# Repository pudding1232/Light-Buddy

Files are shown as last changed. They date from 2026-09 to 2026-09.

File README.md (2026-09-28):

# Light Buddy: Adjustable Flashlight Arm

**An articulating, tool-free arm that holds a pocket flashlight so you can light up a work area and keep both hands free.**

<p align="center">
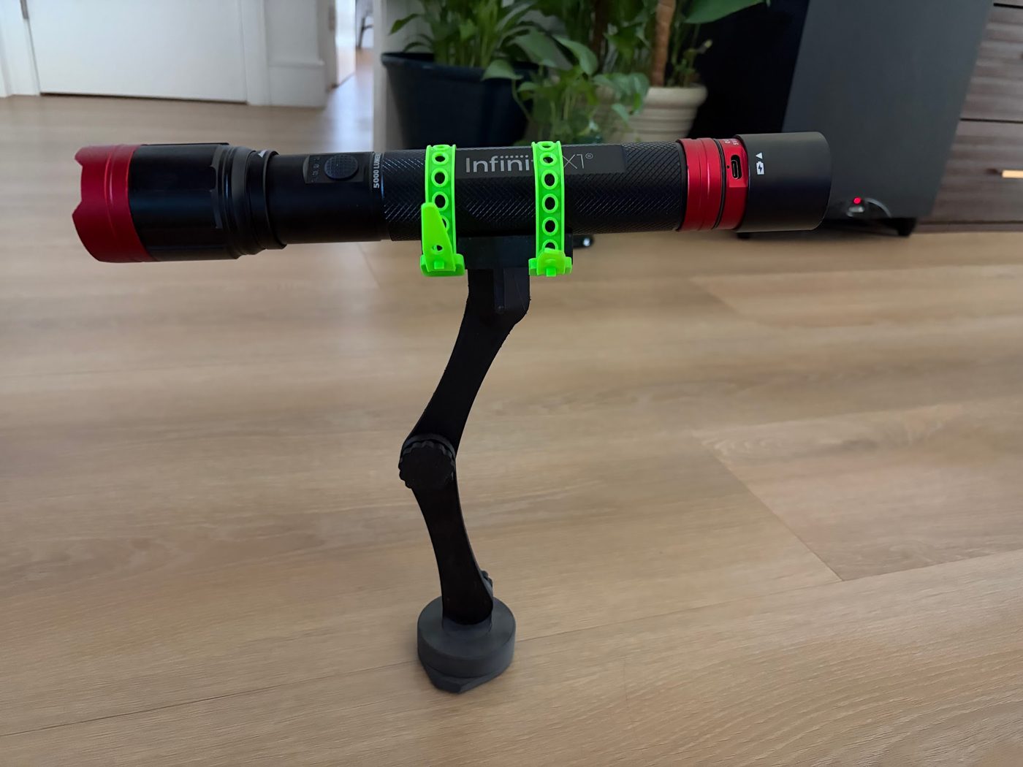
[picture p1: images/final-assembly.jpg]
Final Light Buddy assembly holding a flashlight
  
</p>

| | |
|---|---|
| **Team** | Tran Gia Huy Pham (sole CAD designer), Robert Lopez, Leonardo Valenti |
| **Context** | DMT 56 team project, Critical Design Review (CDR), Spring 2026 |
| **Processes** | FDM (Markforged Onyx + continuous carbon fiber), SLS (Nylon 12), FDM TPU, PolyJet |
| **CAD** | Autodesk Fusion 360: part modeling, assembly, technical drawing, rendered animation |
| **Outcome** | Functional prototype, 114.71 cc total part volume, about $23.88 material cost per unit |

---

## My role

I was the **sole CAD designer** on a three-person team. I modeled every part and the full assembly in **Fusion 360**:

- Designed all components: arm links with **Hirth gear joints**, thumbscrews, the **ratcheting base** with magnet pockets and a removable cap, and the **V-block holder** with integrated strap buckles.
- Carried the design through **three prototype iterations**, reworking the geometry after each round of printing and testing.
- Applied **DfAM** changes, including support structures modeled into the V-block and a locating lip on the base.
- Produced the **assembly drawing with parts list** ([docs/arm-link-assembly-drawing.png](docs/arm-link-assembly-drawing.png)), the renders, and the exploded-view animation.
<!-- Optional: add anything else you personally did (printing, testing, cost analysis). -->

---

## The problem

> *"Design an adjustable arm that allows the user to securely hold a variety of small flashlights in order to illuminate a specific area."*

Professionals and hobbyists often carry a pocket flashlight, but holding it ties up a hand. Light Buddy mounts on a surface, grips a range of flashlight sizes, and can be aimed and locked in place. That leaves both hands free for the work.

## Final design

<p align="center">
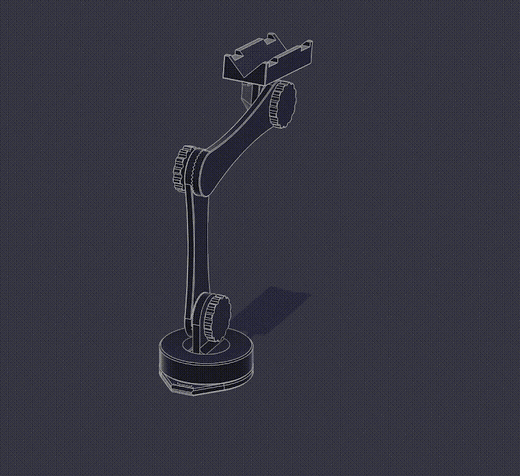
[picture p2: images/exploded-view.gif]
Animated exploded view of the assembly
  
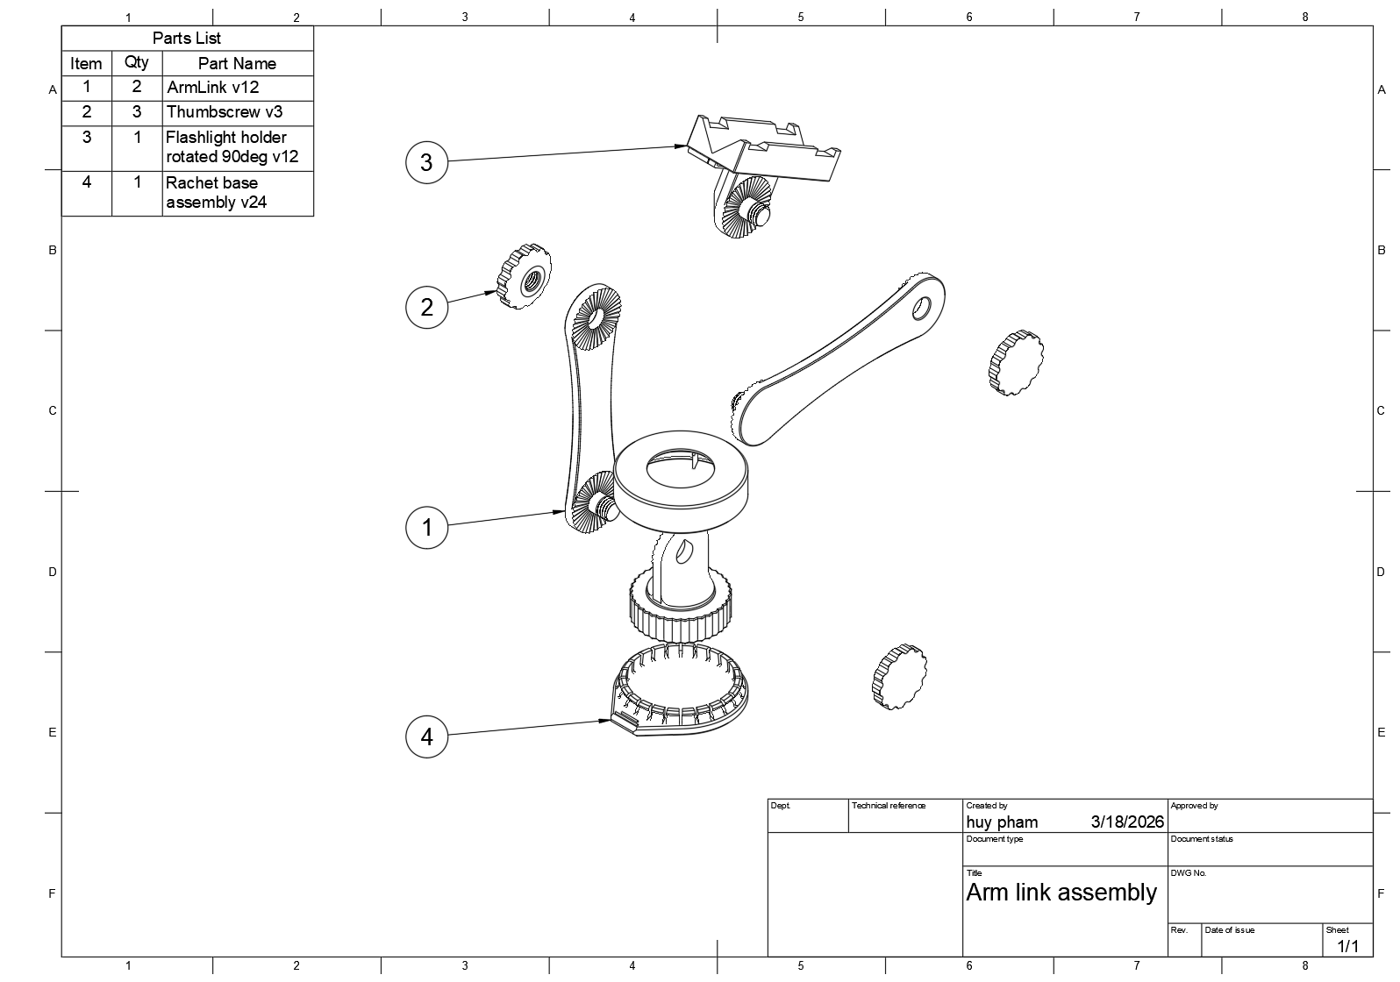
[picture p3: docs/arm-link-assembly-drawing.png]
Arm link assembly drawing with parts list
  
</p>

| Feature | Why it's there |
|---|---|
| **Ratcheting base with removable cap** | Rotates in fixed steps. The cap can be swapped for future base designs. Pockets for insert magnets let it mount on ferrous surfaces. |
| **Hirth gear joints** | Serrated face gears lock at discrete angles, so the arm holds its aim under load. The design is modular, so links can be added to extend the reach. |
| **Thumbscrews** | Every joint adjusts by hand, with no tools needed. |
| **V-block mount + TPU straps** | The V-shape self-centers round bodies of different diameters. Integrated strap buckles clamp the light in place. |

**Parts list:** 2× arm link, 3× thumbscrew, 1× flashlight holder (V-block), 1× ratchet base assembly.

---

## Design iterations

### Prototype V1: proving the joints

<p>
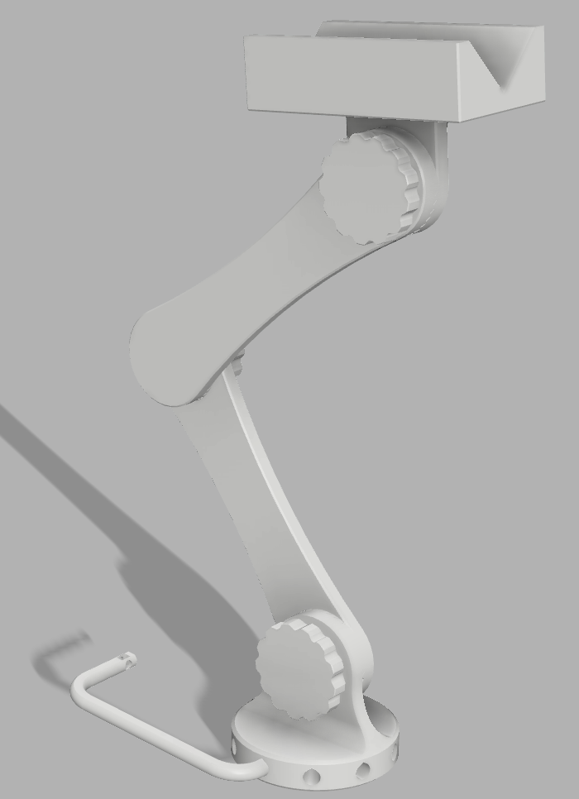
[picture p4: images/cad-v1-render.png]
V1 CAD render
  
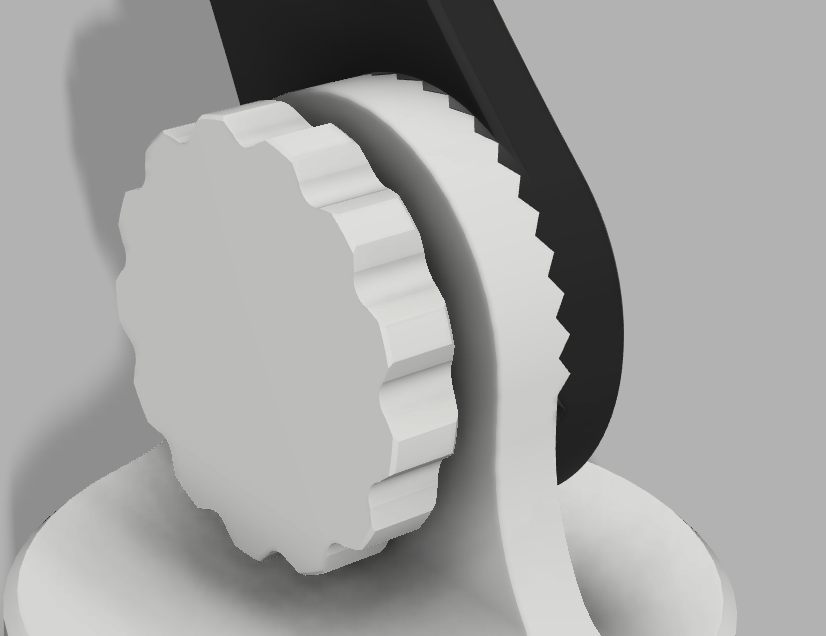
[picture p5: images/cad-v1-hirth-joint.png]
V1 Hirth joint
  
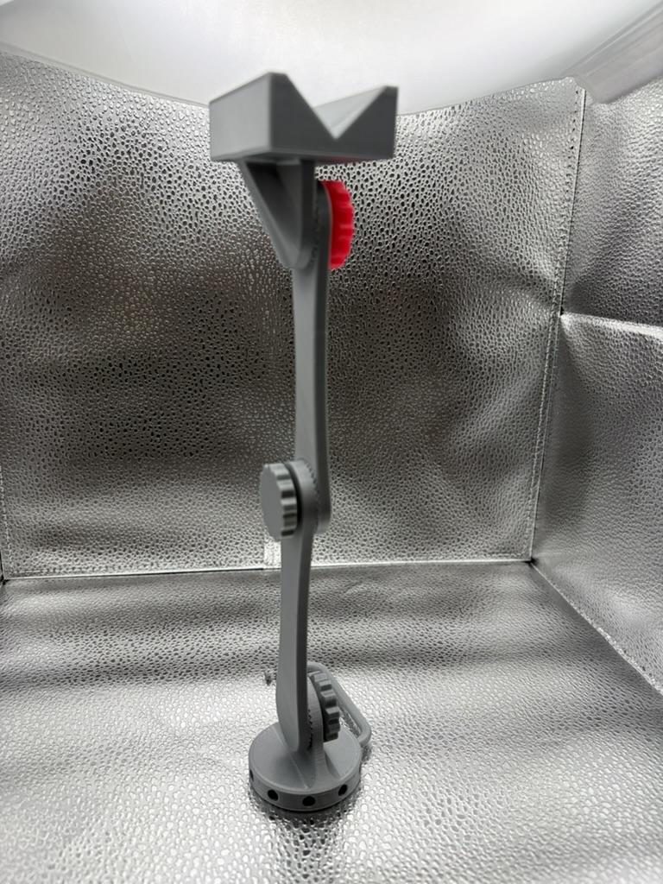
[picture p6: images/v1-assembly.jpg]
V1 printed assembly
  
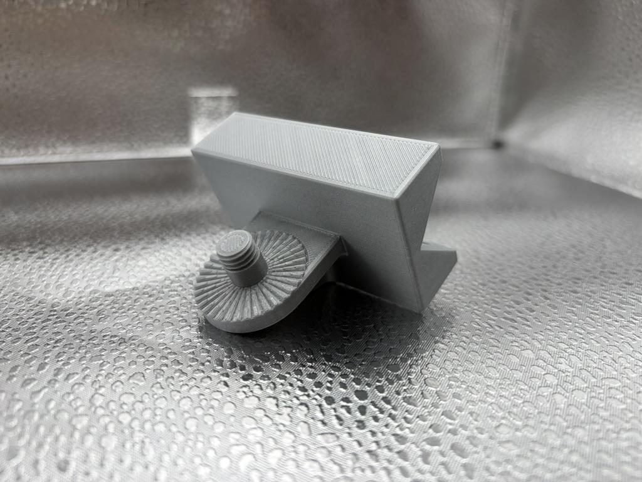
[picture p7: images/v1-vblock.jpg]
V1 printed V-block
  
</p>

- ✅ The Hirth gears and threads worked well.
- ❌ The V-block was bulky, and the base wasn't very functional.

### Prototype V2: a better base and a smaller holder

<p>
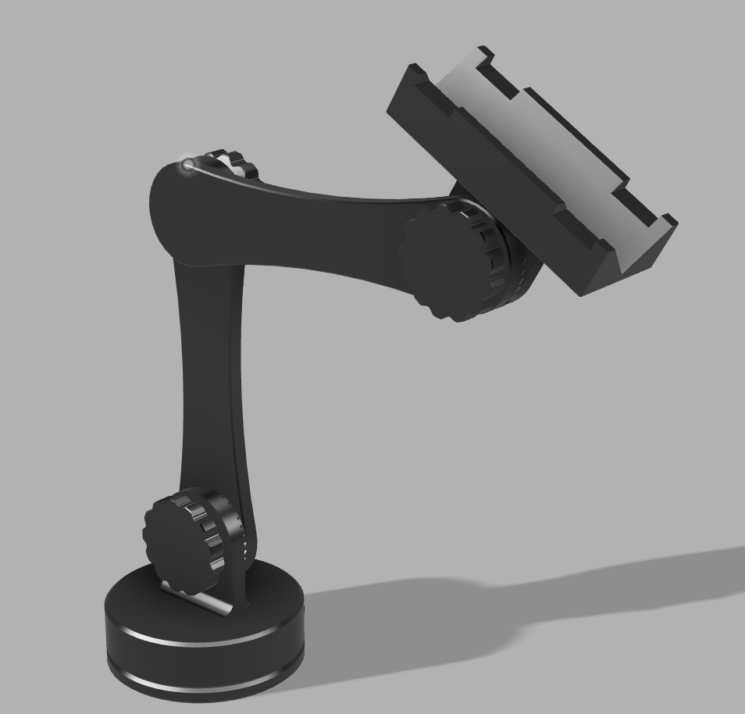
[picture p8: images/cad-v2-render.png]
V2 CAD render
  
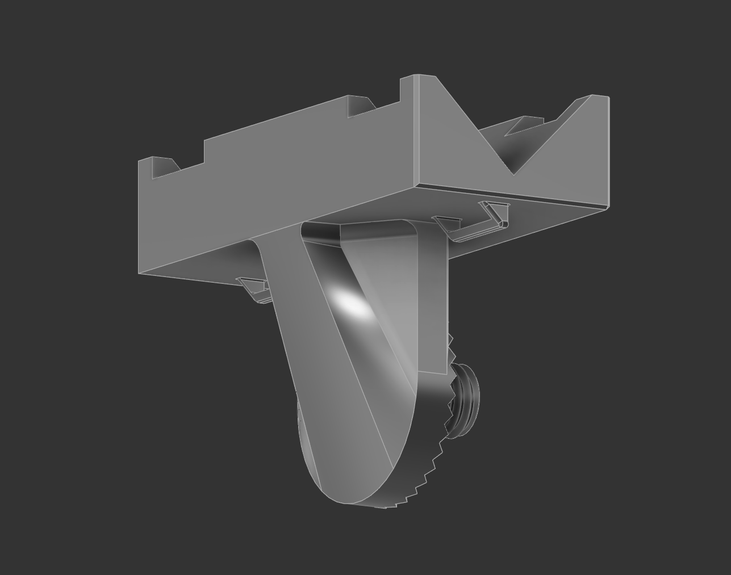
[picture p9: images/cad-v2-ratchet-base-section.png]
V2 ratcheting base section
  
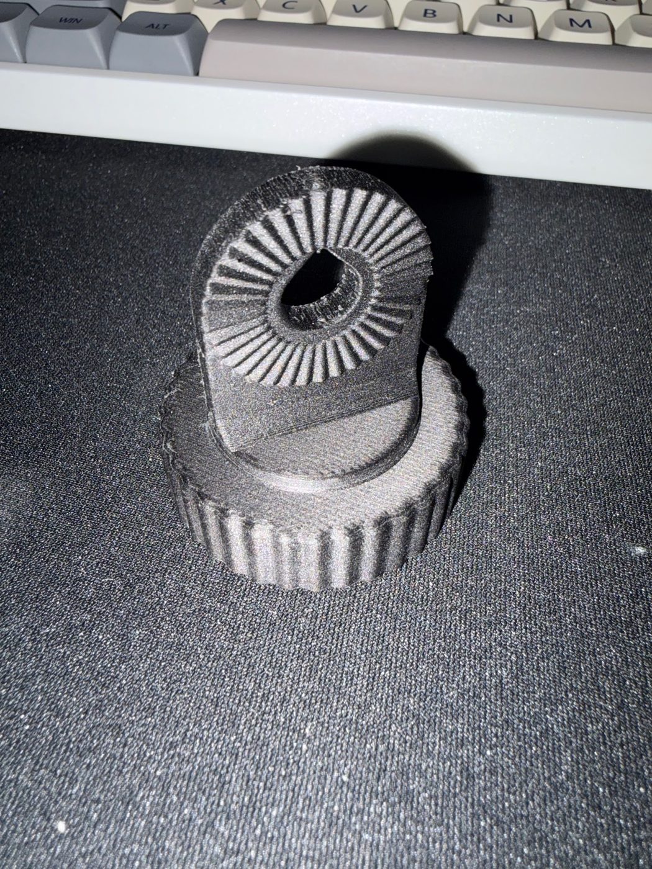
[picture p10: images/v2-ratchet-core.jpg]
V2 printed ratchet core
  
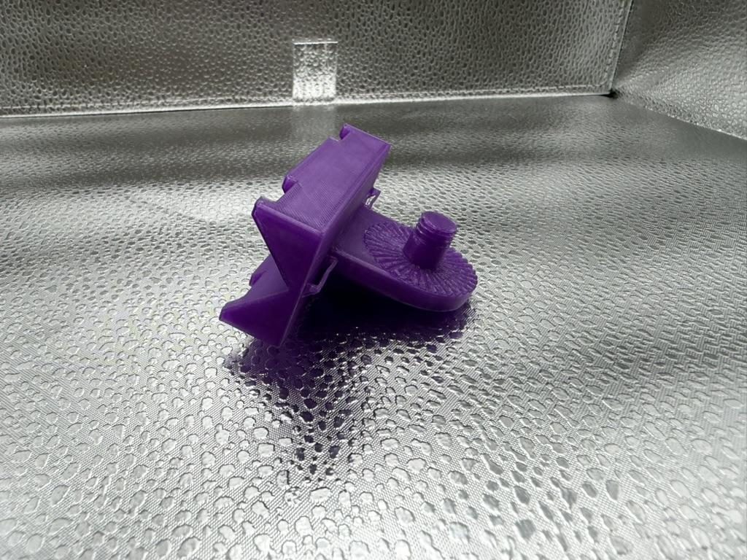
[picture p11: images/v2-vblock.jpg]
V2 printed V-block
  
</p>

- Added a **ratcheting base with integrated magnets**.
- Made the V-block smaller and added **strap loops** to the holder.

### Prototype V3: designing for manufacturing

<p>
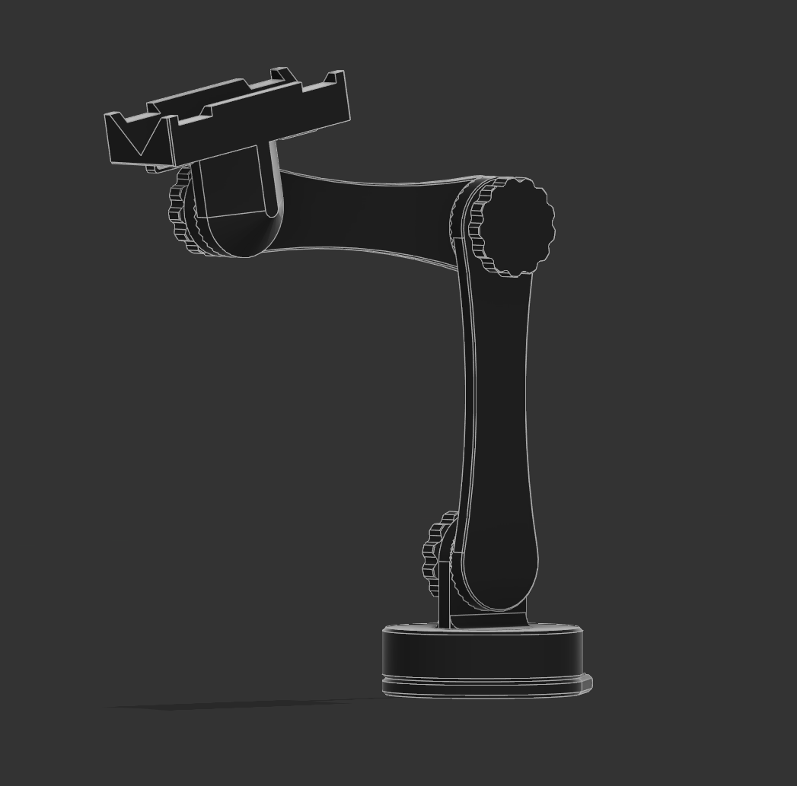
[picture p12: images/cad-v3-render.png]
V3 CAD render
  
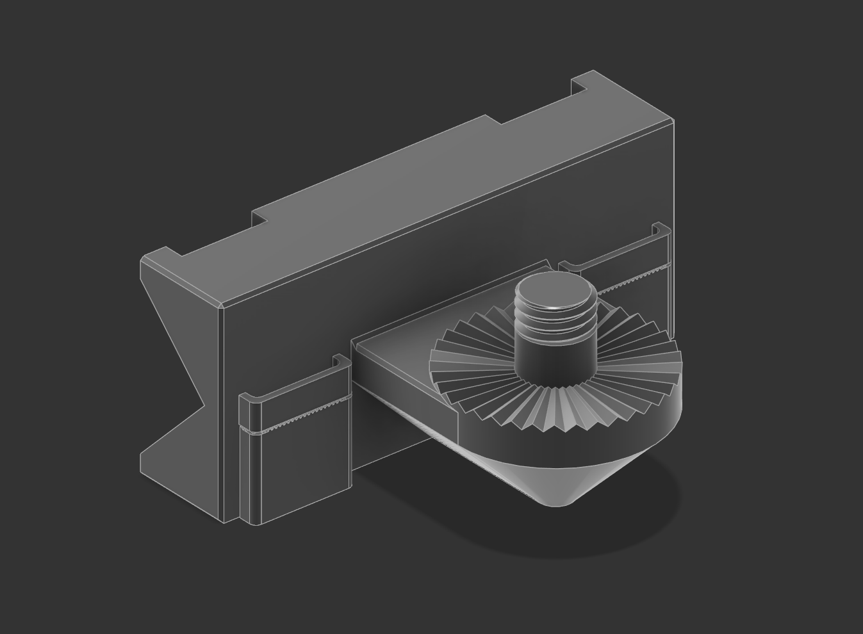
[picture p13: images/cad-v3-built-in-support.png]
V3 built-in support
  
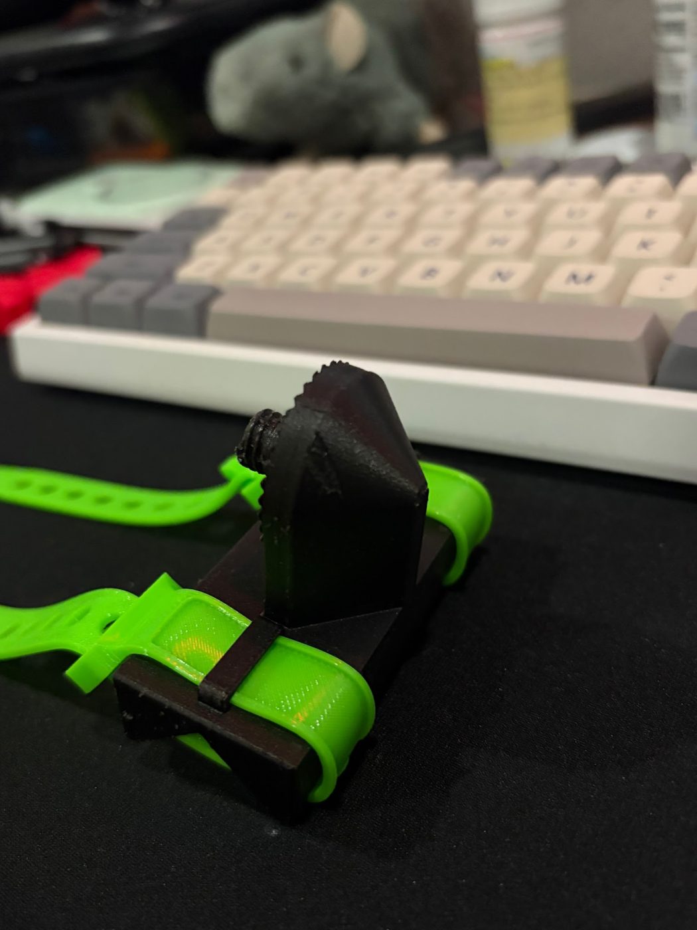
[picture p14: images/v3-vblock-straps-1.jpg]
V3 V-block with TPU straps
  
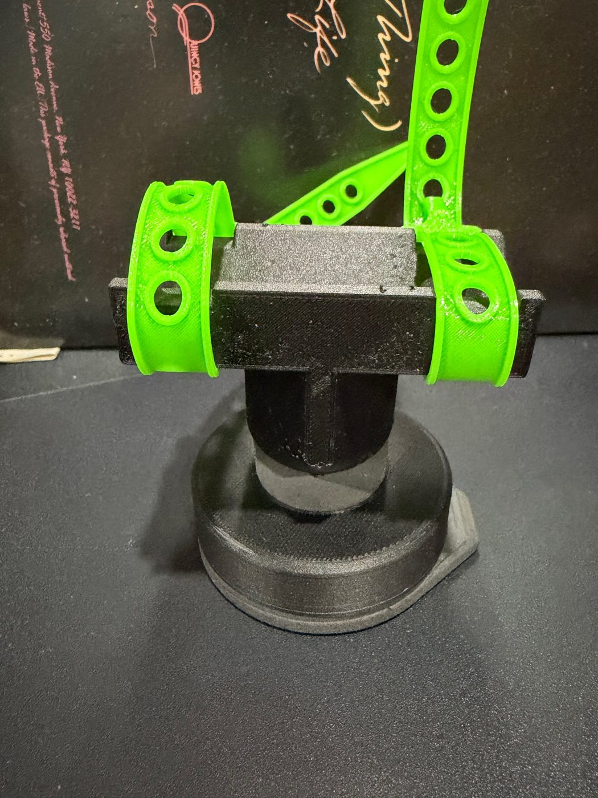
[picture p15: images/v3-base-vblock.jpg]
V3 base and V-block
  
</p>

- Designed **support structures into the V-block model** so it prints cleanly (DfAM).
- Added a **lip to the base** so bases can be swapped more easily.

### V-block evolution (V1 → V3)

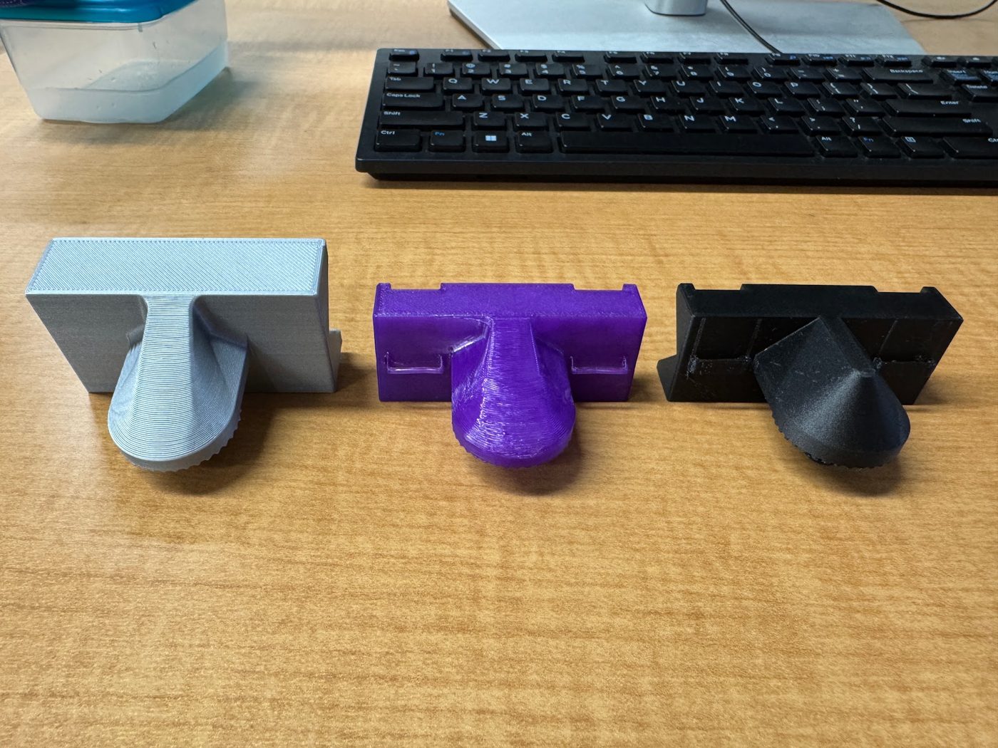
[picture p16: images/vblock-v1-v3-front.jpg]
V-block versions 1, 2 and 3 side by side


---

## Engineering challenges

**Materials**

- **Onyx with continuous carbon fiber** for the arms, for stiffness so the arm stays rigid once it's locked.
- **Flexible Onyx ears** in the ratcheting base, so the ratchet can click.
- **SLS Nylon 12** for the ratchet core and housing cap, for precision and isotropic strength.
- **TPU 95A** for the straps.

**Design for additive manufacturing**

| Problem | Solution |
|---|---|
| The V-block still needed support material | Designed custom support structures into the part |
| The ratchet base cap was fragile and broke easily because of its FDM print orientation | Switched to **SLS** for isotropic properties |
| The ratchet housing was stiff and hard to tune | Open. See [Next steps](#next-steps) |
| Metric threads don't print well | Open |

**Tolerances:** The thumbscrew threads and ratcheting base were the hardest fits to get right, and results from the Markforged printer were inconsistent between prints.

### Failure analysis

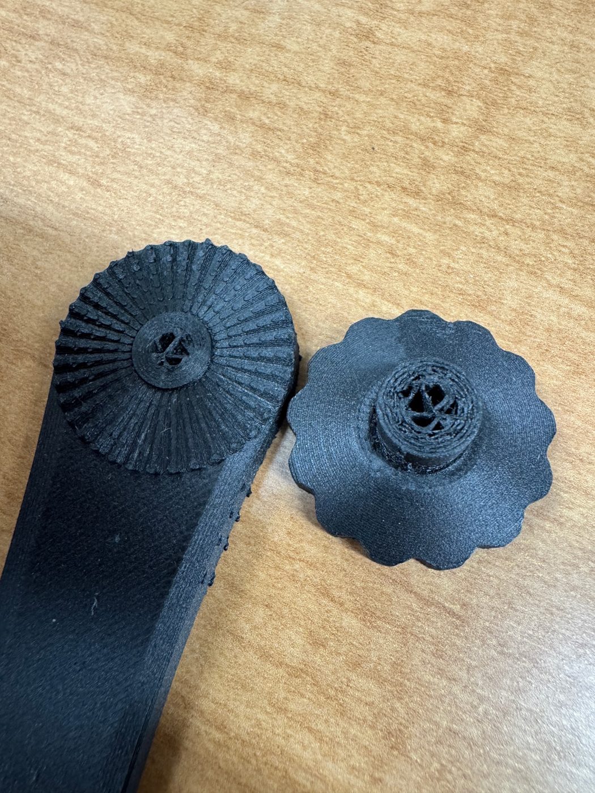
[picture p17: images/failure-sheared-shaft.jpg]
Sheared shaft at the base


Even after the wall count was increased to 6, a shaft **broke near the base**. The cause was poor print accuracy: the threads bound up, and the torque from tightening sheared the shaft. This is why tolerance tuning on the threads became a critical project element.

<br clear="right">

---

## Verification & testing

<p>
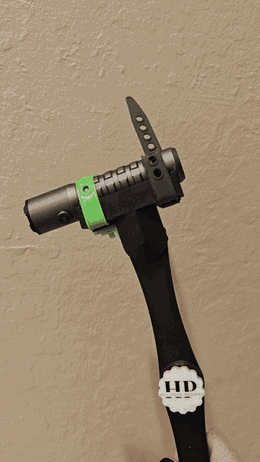
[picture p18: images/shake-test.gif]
Shake test: flashlight stays secured while the arm is shaken
  
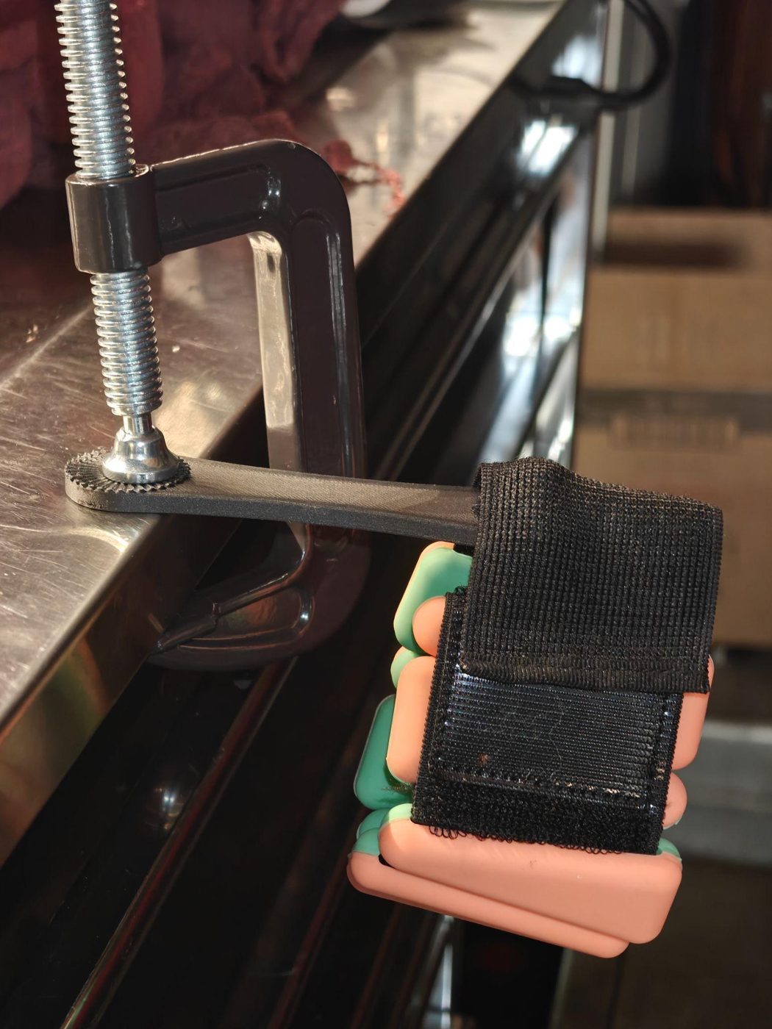
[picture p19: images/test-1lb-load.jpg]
1 lb load test
  
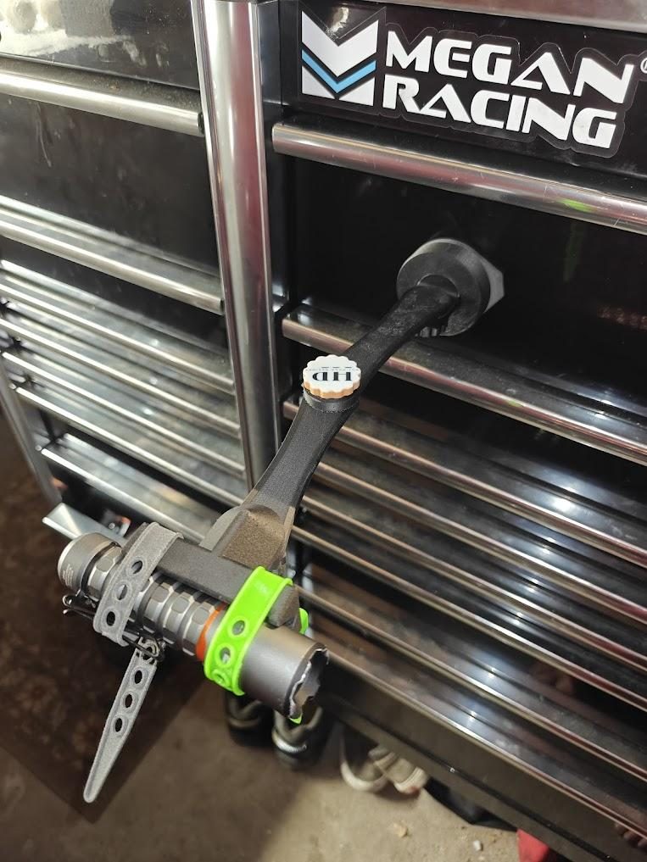
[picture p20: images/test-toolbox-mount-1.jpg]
Mounted magnetically on a toolbox
  
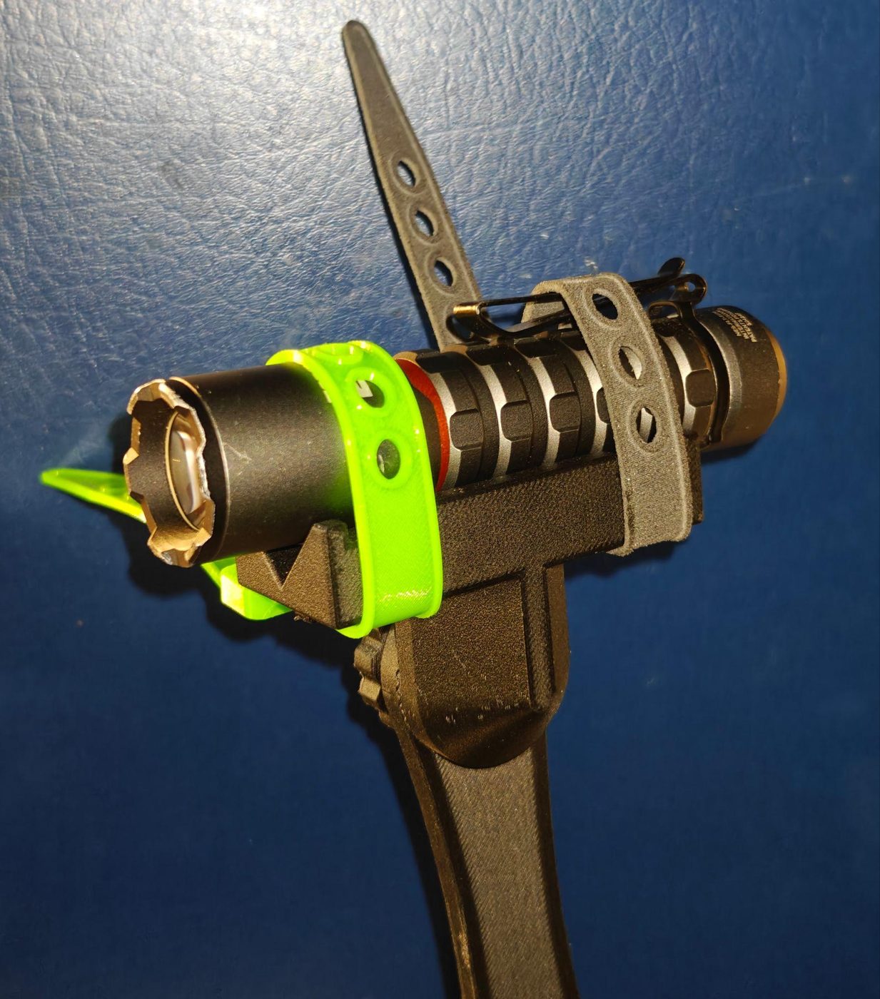
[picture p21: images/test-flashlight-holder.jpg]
Holding a different flashlight
  
</p>

The three critical requirements were: **holds multiple flashlights**, **stays rigid when fixed**, and **can be adjusted repeatedly**. The arm was tested with several flashlights, mounted magnetically on a toolbox, shaken, and loaded with **1 lb**.

| Quantitative requirement | Priority | Result |
|---|---|---|
| Fits within a 5″ × 5″ × 5″ envelope | High | ✅ All dimensions < 5″ |
| Part volume ≤ ⅓ of that envelope (≈ 683 cc) | High | ✅ 114.71 cc (~6% of the envelope) |
| Holds at least 3 types of flashlight | High | ✅ Tested with multiple flashlights |
| Holds about 5 oz | High | ✅ Held 1 lb (16 oz) |
| Joints survive double flashlight weight (about 10 oz) | Medium | ✅ Held 1 lb (16 oz) |
| At least 3 axes of adjustment | Medium | ✅ 3 Hirth joints + rotating ratchet base |
| Setup in about 20 s | Low | ✅ About 10 s |
| Extended arm length about 10 in | Low | ⚠️ About 5 in (see note) |

**Note on arm length:** The arm reaches about 5 in, short of the 10 in target. That target conflicted with two high-priority requirements: the whole product had to fit in a 5″ cube and use no more than a third of its volume. We kept the envelope, and because the arm links are modular, more links can be added for extra reach.

<details>
<summary>Qualitative requirements</summary>

| Requirement | Priority |
|---|---|
| Demonstrates fit with another object, or has multiple components that fit together | High |
| Serves a function other than visual | High |
| Rigid when fixed; doesn't sag over time | High |
| Holds the flashlight firmly; the light stays in place once tightened | High |
| Attaches to multiple surfaces, both magnetic and non-magnetic | Medium |
| Thin folded form factor that fits a medium pocket | Medium |
| Can be adjusted with one hand | Low |
| Collapsible and modular, with swappable parts | Low |
| Simple appearance suitable for professional use | Low |

</details>

---

## Cost & production

| # | Part | Process | Material | Volume (cc) | Cost ($) |
|---|---|---|---|---|---|
| 1 | Arm (×2) | FDM | Onyx + continuous CF | 24.70 + 1.94 CF | 11.68 |
| 2 | Nut (×3) | FDM | Onyx | 7.72 | 1.83 |
| 3 | V-block holder | FDM | Onyx | 18.24 | 4.33 |
| 4 | Ratchet housing | FDM | Onyx | 7.38 | 1.75 |
| 5 | Housing cap | SLS | Nylon 12 | 20.00 | 1.58 |
| 6 | Ratchet core | SLS | Nylon 12 | 26.50 | 2.55 |
| 7 | TPU straps (×2) | FDM | TPU 95A | 8.23 | 0.16 |
| | **Total** | | | **114.71** | **$23.88** |

### Customization concept

<p>
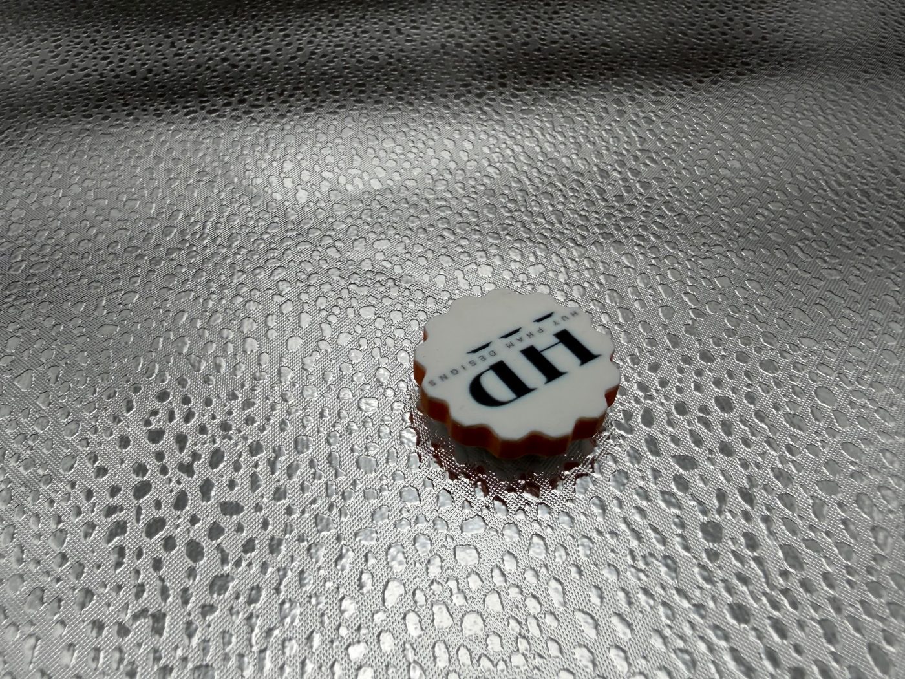
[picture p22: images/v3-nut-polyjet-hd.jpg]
PolyJet printed custom nut
  
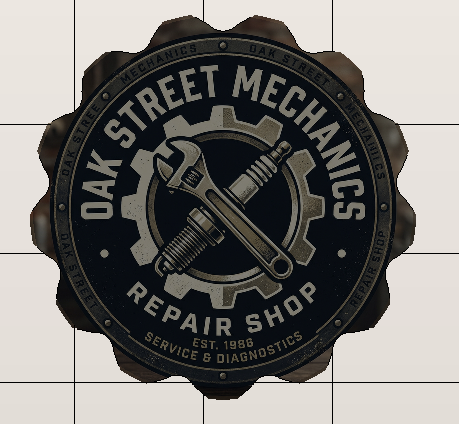
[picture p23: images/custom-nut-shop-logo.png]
Custom nut with shop logo
  
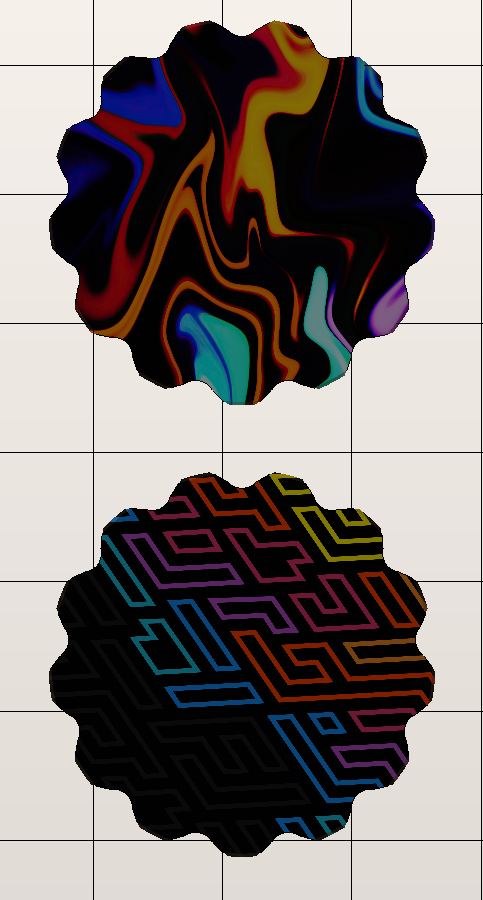
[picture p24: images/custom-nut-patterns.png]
Custom nut patterns
  
</p>

Tradespeople often mark their tools so they don't get mixed up on a job site, and shops like to brand their equipment. Buyers could keep the standard black FDM thumbscrew nuts or pay extra for 1–3 **full-color PolyJet nuts** with a logo or graphic. PolyJet makes one-off customization affordable at a scale that traditional manufacturing can't match.

---

## Next steps

Planned improvements, focused on the base mount:

- A stronger hold
- More mounting styles
- A better ratcheting mechanism, or a set screw
- A grippier base to prevent slipping and rotating

---

## Repository contents

```
light-buddy/
├── README.md
├── cad/        STEP + STL files for each part
├── docs/       Assembly drawing (and CDR slides)
└── images/     Photos, renders, and animations used above
```

## Team

Tran Gia Huy Pham · Robert Lopez · Leonardo Valenti

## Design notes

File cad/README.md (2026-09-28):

# CAD files

Add your exported part files here so reviewers can open them without your CAD software. GitHub shows `.stl` files in an interactive 3D viewer.

Suggested files (names match the assembly drawing):

| Part | Qty | STEP | STL |
|---|---|---|---|
| Arm link | 2 | `arm-link.step` | `arm-link.stl` |
| Thumbscrew nut | 3 | `thumbscrew.step` | `thumbscrew.stl` |
| Flashlight holder (V-block) | 1 | `vblock-holder.step` | `vblock-holder.stl` |
| Ratchet housing | 1 | `ratchet-housing.step` | `ratchet-housing.stl` |
| Ratchet core | 1 | `ratchet-core.step` | `ratchet-core.stl` |
| Housing cap | 1 | `housing-cap.step` | `housing-cap.stl` |
| TPU strap | 2 | `tpu-strap.step` | `tpu-strap.stl` |
| Full assembly | — | `light-buddy-assembly.step` | — |

Keep each file under 100 MB. GitHub blocks larger files.

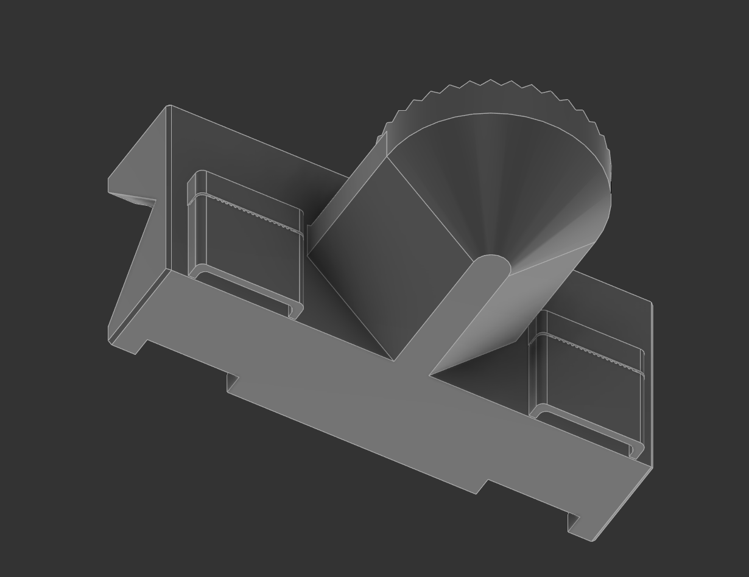
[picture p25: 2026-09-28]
images/cad-v3-support-detail.png

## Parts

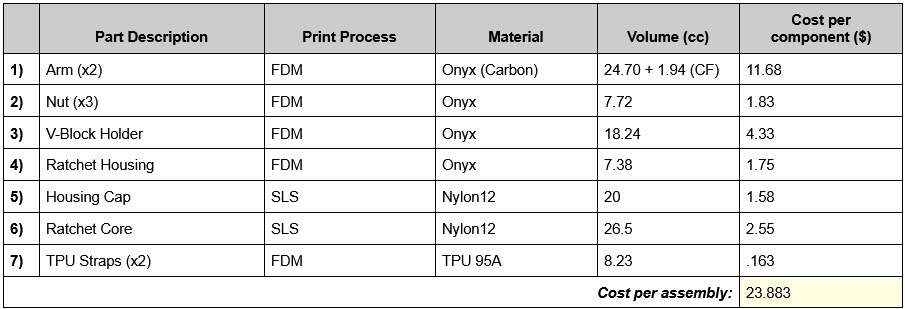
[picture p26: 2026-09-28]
images/cost-table.png

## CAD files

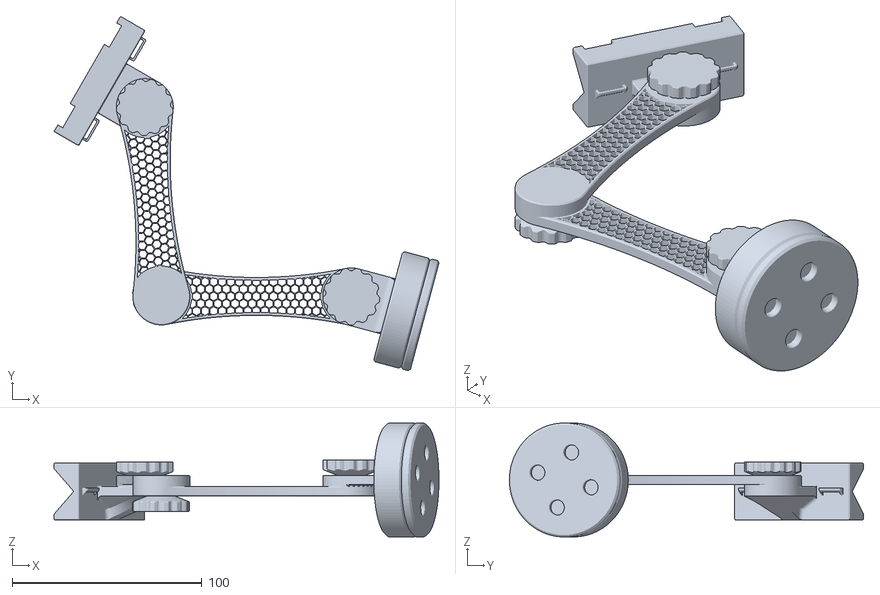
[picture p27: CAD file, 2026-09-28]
cad/Arm link assembly.stl
202.7 x 186.5 x 60.0

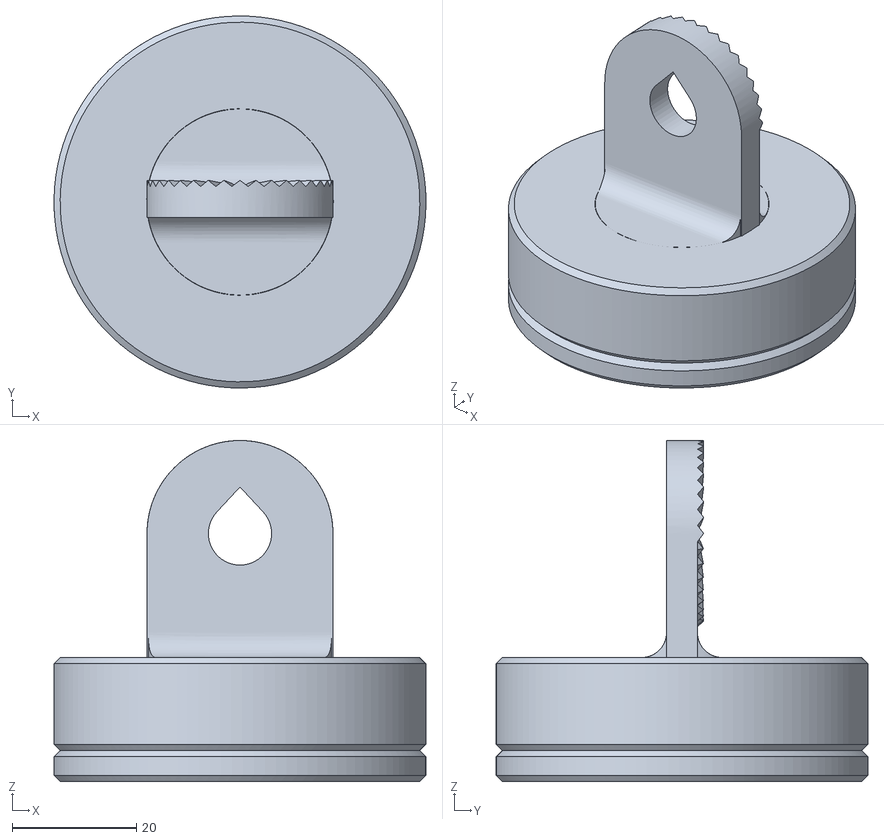
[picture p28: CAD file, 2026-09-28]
cad/rachet base assembly.stl
60.0 x 60.0 x 55.0

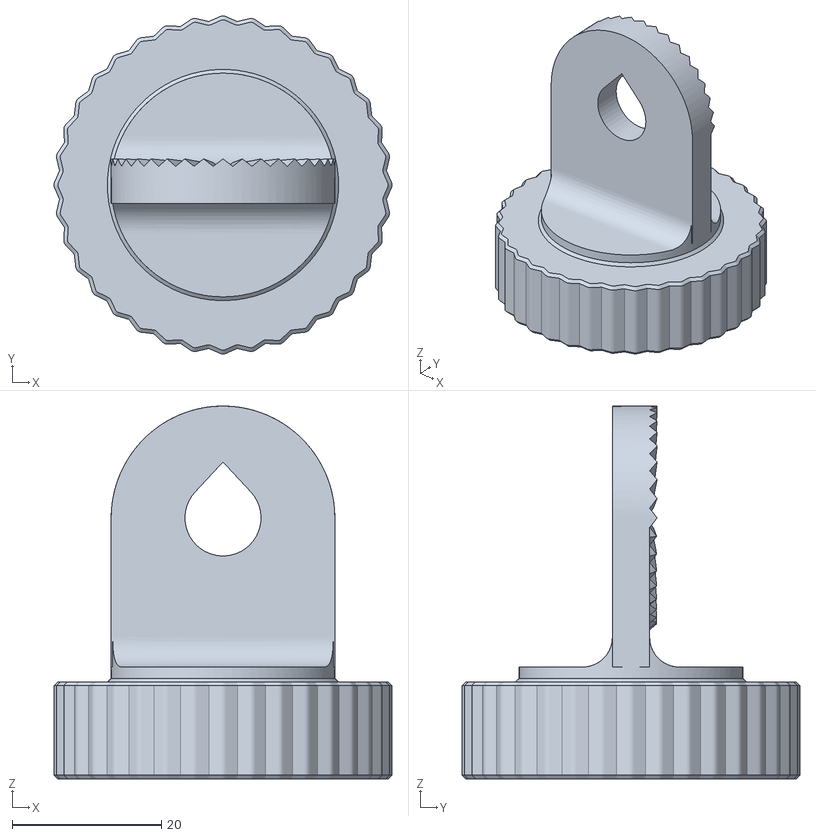
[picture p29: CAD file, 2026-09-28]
cad/racheting base.stl
45.3 x 45.3 x 50.0

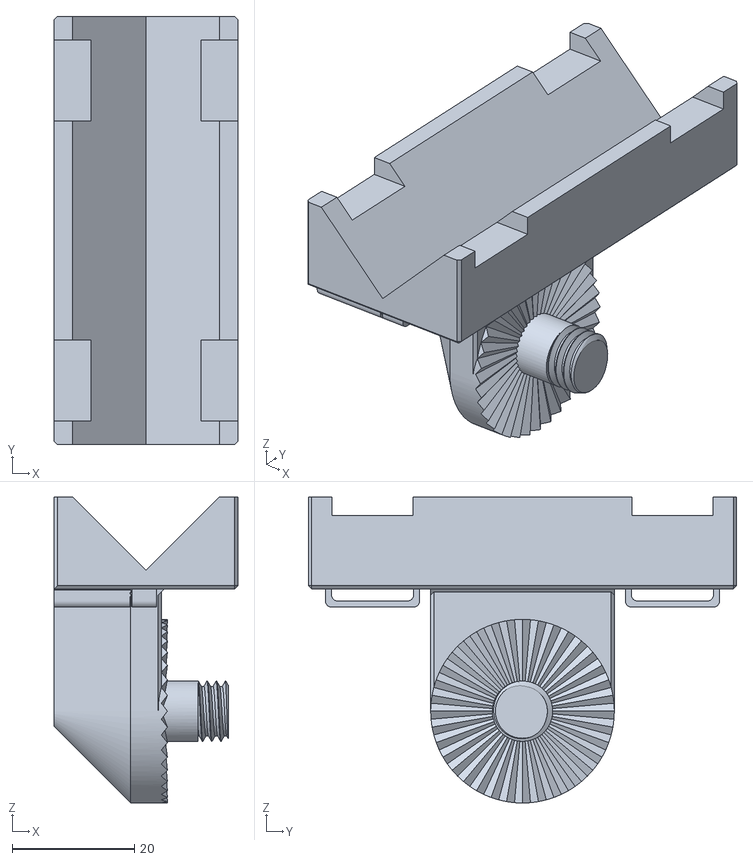
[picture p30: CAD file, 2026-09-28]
cad/flashlight holder rotated 90deg.stl
30.0 x 70.0 x 50.0

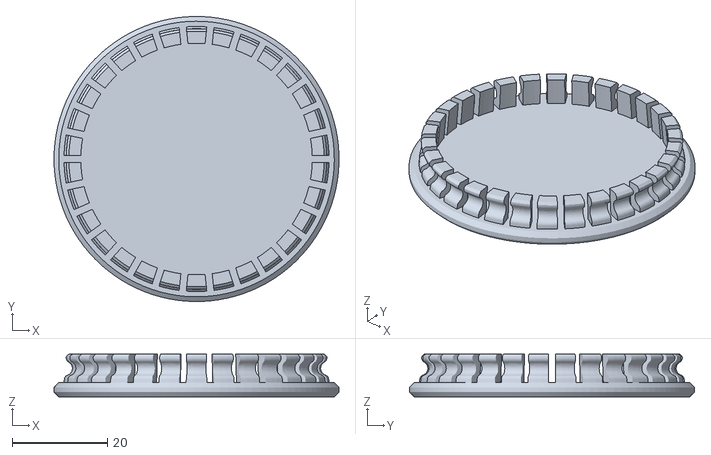
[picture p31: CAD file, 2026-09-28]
cad/cap.stl
60.0 x 60.0 x 9.00

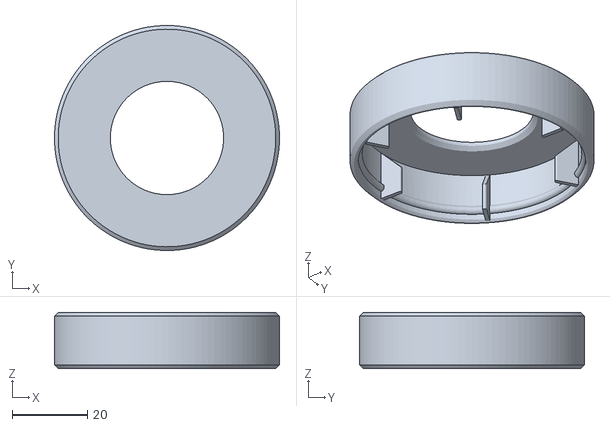
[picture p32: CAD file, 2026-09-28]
cad/racheting top housing.stl
60.0 x 60.0 x 15.0

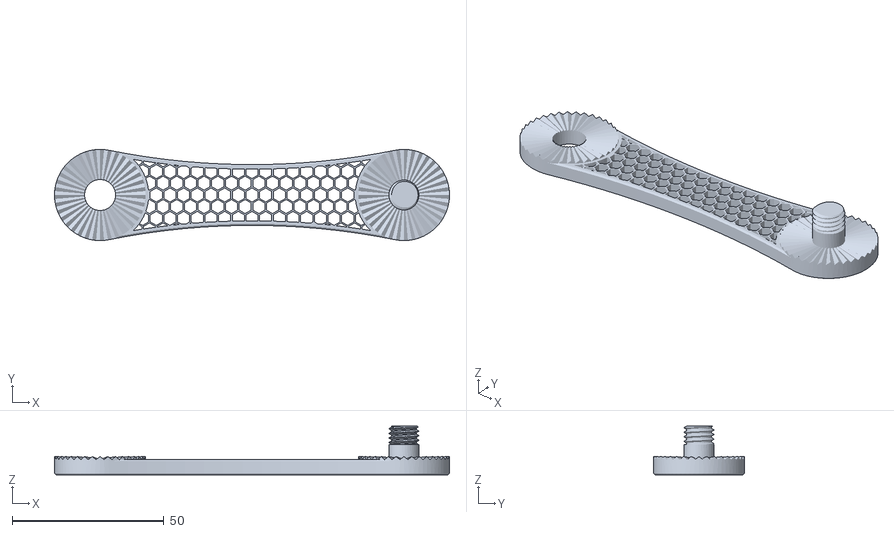
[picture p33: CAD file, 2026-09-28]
cad/ArmLink with holes.stl
130.0 x 30.0 x 16.0

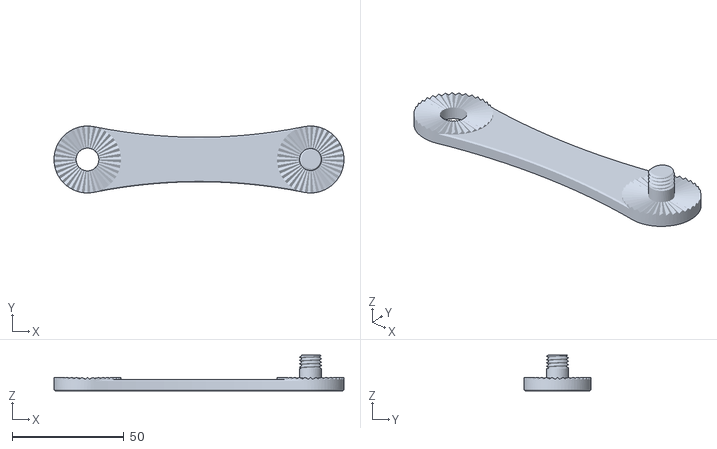
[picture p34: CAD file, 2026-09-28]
cad/ArmLink.stl
130.0 x 30.0 x 16.0

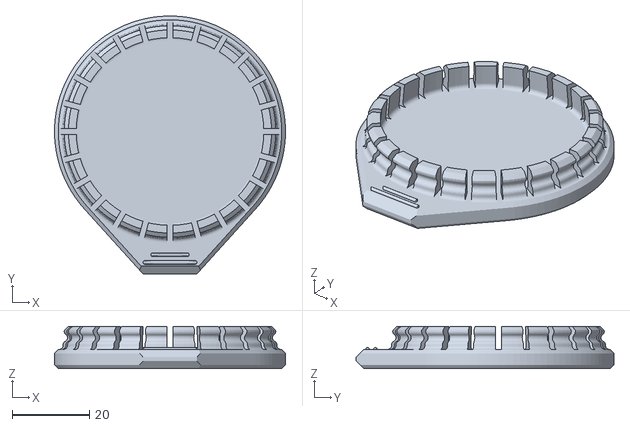
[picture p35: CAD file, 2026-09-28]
cad/cap with magnets.stl
60.0 x 67.0 x 11.0

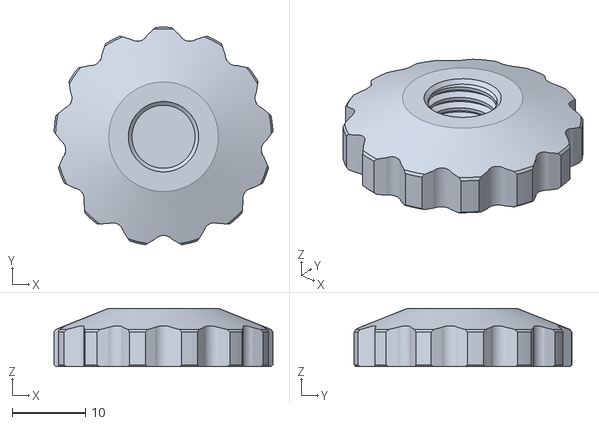
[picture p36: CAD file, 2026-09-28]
cad/Thumbscrew.stl
30.0 x 29.8 x 8.00

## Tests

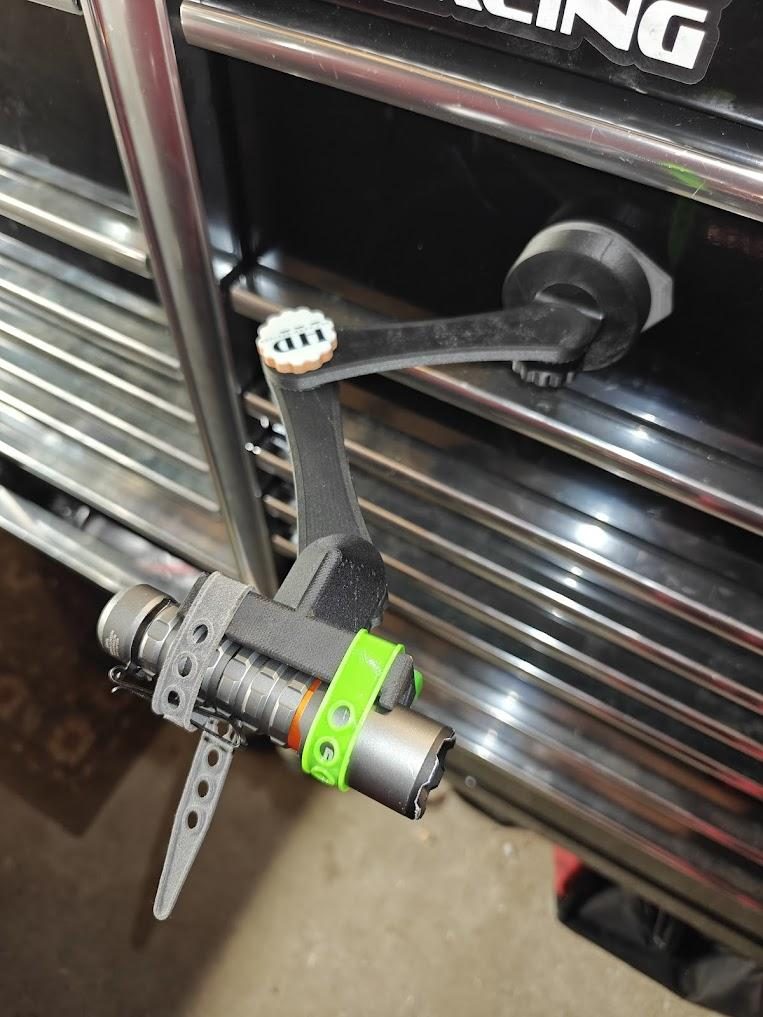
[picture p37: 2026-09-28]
images/test-toolbox-mount-2.jpg
